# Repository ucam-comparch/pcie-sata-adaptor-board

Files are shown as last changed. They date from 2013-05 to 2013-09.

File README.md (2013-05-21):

This is a printed circuit board to breakout an 8-lane PCI Express socket into
8x SATA channels, which we have used with Terasic DE4 FPGA boards.

THIS IS NOT A SATA CONTROLLER, it merely uses SATA sockets for the physical
connections as the sockets and cables are cheap, and have good signal integrity.
What you put down the PCIe lanes is up to your FPGA configuration.

Images (the first version with a few hand bugfixes):
Front board image
Rear board image

The design was created using Eagle PCB, but the gerber files should be
usable even if you don't have Eagle.

The 4-layer board was fabricated by rak.co.uk using a standard-ish stackup:  
0.2mm double sided  
2 pre-pregs (0.15mm)  
0.8mm unclad board  
2 pre-pregs (0.15mm)  
0.2mm double sided  
Total 1.5-1.6mm  

They don't provide controlled impedance boards but our design is sized to
have the correct impedances according to this stackup.

In addition ports are provided for:  
SATA power (3.3V and 12V)  
Altera USB Blaster-compatible JTAG port  

Since we couldn't source SATA power connectors without data, the data part
of the SATA power connector is connected to some I/Os on the PCIe connector. 
This can be used for low-speed signalling from the FPGA.

If you connect a USB Blaster to the JTAG port you need to fit components to
VREF_SRC to supply the correct VREF.  The DE4 uses 2.5V - we fit resistors
68R from 3V3 to VREF and 220R from VREF to ground.

R1/R2/R3 provide access to the unused lines on the JTAG cable, or means to
ground them to reduce noise.

Computer Architecture Group, University of Cambridge Computer Laboratory  
May 2013  
http://www.cl.cam.ac.uk/research/comparch/  

Copyright (c) 2013, Simon Moore  
All rights reserved.  

Redistribution and use in source and binary forms, with or without
modification, are permitted provided that the following conditions are met:

 1. Redistributions of source code must retain the above copyright notice, this
    list of conditions and the following disclaimer.

 2. Redistributions in binary form must reproduce the above copyright
    notice, this list of conditions and the following disclaimer in the
    documentation and/or other materials provided with the distribution.

THIS SOFTWARE IS PROVIDED BY THE COPYRIGHT HOLDERS AND CONTRIBUTORS "AS IS"
AND ANY EXPRESS OR IMPLIED WARRANTIES, INCLUDING, BUT NOT LIMITED TO,
THE IMPLIED WARRANTIES OF MERCHANTABILITY AND FITNESS FOR A PARTICULAR
PURPOSE ARE DISCLAIMED.  IN NO EVENT SHALL THE COPYRIGHT HOLDER OR
CONTRIBUTORS BE LIABLE FOR ANY DIRECT, INDIRECT, INCIDENTAL, SPECIAL,
EXEMPLARY, OR CONSEQUENTIAL DAMAGES (INCLUDING, BUT NOT LIMITED TO,
PROCUREMENT OF SUBSTITUTE GOODS OR SERVICES; LOSS OF USE, DATA, OR
PROFITS; OR BUSINESS INTERRUPTION) HOWEVER CAUSED AND ON ANY THEORY OF
LIABILITY, WHETHER IN CONTRACT, STRICT LIABILITY, OR TORT (INCLUDING
NEGLIGENCE OR OTHERWISE) ARISING IN ANY WAY OUT OF THE USE OF THIS
SOFTWARE, EVEN IF ADVISED OF THE POSSIBILITY OF SUCH DAMAGE.

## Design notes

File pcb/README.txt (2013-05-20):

File extensions:
Eagle schematic: .sch
Eagle board: .brd
Eagle library: .lbr

Gerber layers:
.crc: component side solder cream frame
.plc: component side silkscreen
.stc: component side solder mask
.cmp: component side copper
.ly2: inner layer copper (layer 2)
.l15: inner layer copper (layer 15)
.sol: solder side copper
.sts: solder side solder mask
.pls: solder side silkscreen
.crs: solder side solder cream frame

Drill files:
.drd: Excellon drill file
.dri: Drill station info file

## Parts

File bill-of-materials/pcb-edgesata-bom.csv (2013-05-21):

PCIe to SATA adaptor PCB parts list
User part no | Supplier | Supplier part no | Qty per assembly | Description | Mfr/Part | Unit price exc breaks | Total price | Notes
 | Farnell | 1753904 | 1 | SOCKET, PCI-E, 2X49, EDGE | SAMTEC - PCIE-098-02-F-D-EM2 | 7.98 | 7.98
 | Farnell | 1519801 | 8 | HEADER, SATA, VERTICAL, 1.27MM, 7WAY | MOLEX - 47155-4001 | 0.28 | 2.24
 | RS | 212-806 | 1 | SATA 22P DEVICE PLUG RIGHT ANGLE PTH | 3M 5622-4100-ML | 1.772 | 1.772
 | Farnell | 1099245 | 1 | HEADER, RIGHT ANGLE, 10WAY | MULTICOMP - MC9A22-1034 | 0.39 | 0.39
 | Farnell | 3418492 | 2 | HEADER, 2ROW, 6WAY | TE CONNECTIVITY / AMP 826632-3 | 0.22 | 0.44
0R-0805 |  |  | 3 | 0R 0805 resistor |  |  |  | Optional
 | RAK |  | 1 | Printed circuit board | UNI14 - 97956

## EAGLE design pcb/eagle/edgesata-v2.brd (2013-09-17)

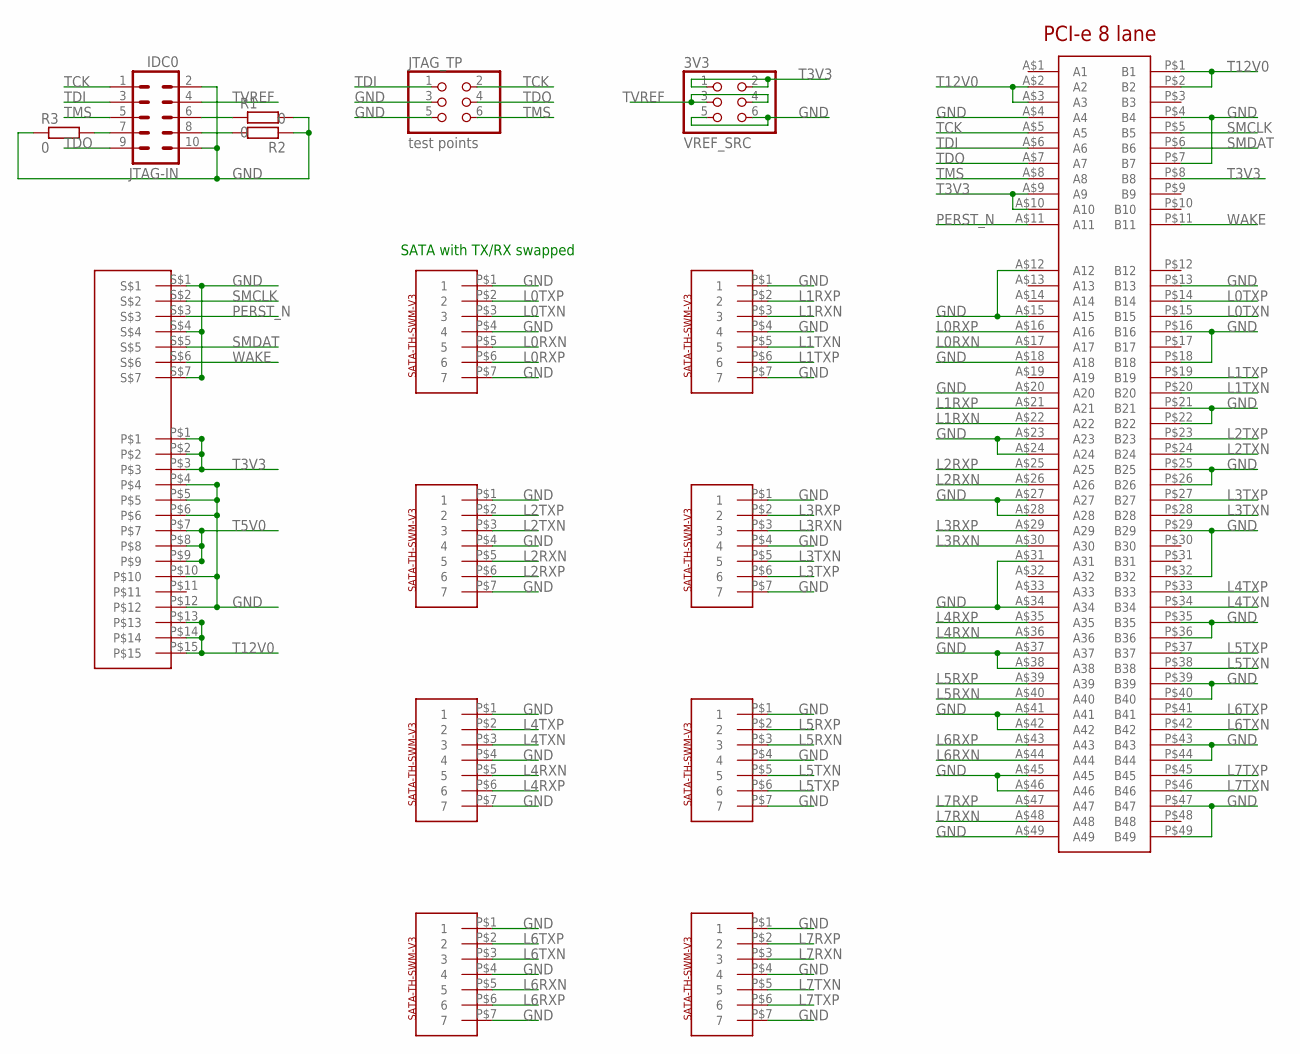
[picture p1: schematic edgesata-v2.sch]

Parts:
3V3: VREF_SRC; 2X03
JTAG-IN: IDC0; MA05-2
JTAG_TP: test points; 2X03
LANE0, LANE1, LANE2, LANE3, LANE4, LANE5, LANE6, LANE7: SATA-TH-SWM-V3
R1, R2, R3: 0; R0805W
U$1: SATA-POWER-V1
U$8: PCIE-EDGE-8LANE-V1

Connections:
GND: 3V3.5, 3V3.6, JTAG-IN.2, JTAG-IN.10, JTAG_TP.3, JTAG_TP.5, LANE0.P$1 (1), LANE0.P$4 (4), LANE0.P$7 (7), LANE1.P$1 (1), LANE1.P$4 (4), LANE1.P$7 (7), LANE2.P$1 (1), LANE2.P$4 (4), LANE2.P$7 (7), LANE3.P$1 (1), LANE3.P$4 (4), LANE3.P$7 (7), LANE4.P$1 (1), LANE4.P$4 (4), LANE4.P$7 (7), LANE5.P$1 (1), LANE5.P$4 (4), LANE5.P$7 (7), LANE6.P$1 (1), LANE6.P$4 (4), LANE6.P$7 (7), LANE7.P$1 (1), LANE7.P$4 (4), LANE7.P$7 (7), R1.2, R2.1, R3.1, U$1.P$4, U$1.P$5, U$1.P$6, U$1.P$10, U$1.P$12, U$1.S$1, U$1.S$4, U$1.S$7, U$8.A$4 (A4), U$8.A$12 (A12), U$8.A$15 (A15), U$8.A$18 (A18), U$8.A$20 (A20), U$8.A$23 (A23), U$8.A$24 (A24), U$8.A$27 (A27), U$8.A$28 (A28), U$8.A$31 (A31), U$8.A$34 (A34), U$8.A$37 (A37), U$8.A$38 (A38), U$8.A$41 (A41), U$8.A$42 (A42), U$8.A$45 (A45), U$8.A$46 (A46), U$8.A$49 (A49), U$8.P$4 (B4), U$8.P$7 (B7), U$8.P$13 (B13), U$8.P$16 (B16), U$8.P$18 (B18), U$8.P$21 (B21), U$8.P$22 (B22), U$8.P$25 (B25), U$8.P$26 (B26), U$8.P$29 (B29), U$8.P$32 (B32), U$8.P$35 (B35), U$8.P$36 (B36), U$8.P$39 (B39), U$8.P$40 (B40), U$8.P$43 (B43), U$8.P$44 (B44), U$8.P$47 (B47), U$8.P$49 (B49)
L0RXN: LANE0.P$5 (5), U$8.A$17 (A17)
L0RXP: LANE0.P$6 (6), U$8.A$16 (A16)
L0TXN: LANE0.P$3 (3), U$8.P$15 (B15)
L0TXP: LANE0.P$2 (2), U$8.P$14 (B14)
L1RXN: LANE1.P$3 (3), U$8.A$22 (A22)
L1RXP: LANE1.P$2 (2), U$8.A$21 (A21)
L1TXN: LANE1.P$5 (5), U$8.P$20 (B20)
L1TXP: LANE1.P$6 (6), U$8.P$19 (B19)
L2RXN: LANE2.P$5 (5), U$8.A$26 (A26)
L2RXP: LANE2.P$6 (6), U$8.A$25 (A25)
L2TXN: LANE2.P$3 (3), U$8.P$24 (B24)
L2TXP: LANE2.P$2 (2), U$8.P$23 (B23)
L3RXN: LANE3.P$3 (3), U$8.A$30 (A30)
L3RXP: LANE3.P$2 (2), U$8.A$29 (A29)
L3TXN: LANE3.P$5 (5), U$8.P$28 (B28)
L3TXP: LANE3.P$6 (6), U$8.P$27 (B27)
L4RXN: LANE4.P$5 (5), U$8.A$36 (A36)
L4RXP: LANE4.P$6 (6), U$8.A$35 (A35)
L4TXN: LANE4.P$3 (3), U$8.P$34 (B34)
L4TXP: LANE4.P$2 (2), U$8.P$33 (B33)
L5RXN: LANE5.P$3 (3), U$8.A$40 (A40)
L5RXP: LANE5.P$2 (2), U$8.A$39 (A39)
L5TXN: LANE5.P$5 (5), U$8.P$38 (B38)
L5TXP: LANE5.P$6 (6), U$8.P$37 (B37)
L6RXN: LANE6.P$5 (5), U$8.A$44 (A44)
L6RXP: LANE6.P$6 (6), U$8.A$43 (A43)
L6TXN: LANE6.P$3 (3), U$8.P$42 (B42)
L6TXP: LANE6.P$2 (2), U$8.P$41 (B41)
L7RXN: LANE7.P$3 (3), U$8.A$48 (A48)
L7RXP: LANE7.P$2 (2), U$8.A$47 (A47)
L7TXN: LANE7.P$5 (5), U$8.P$46 (B46)
L7TXP: LANE7.P$6 (6), U$8.P$45 (B45)
unnamed: JTAG-IN.7, R3.2
unnamed: JTAG-IN.6, R1.1
unnamed: JTAG-IN.8, R2.2
PERST_N: U$1.S$3, U$8.A$11 (A11)
SMCLK: U$1.S$2, U$8.P$5 (B5)
SMDAT: U$1.S$5, U$8.P$6 (B6)
T3V3: 3V3.1, 3V3.2, U$1.P$1, U$1.P$2, U$1.P$3, U$8.A$9 (A9), U$8.A$10 (A10), U$8.P$8 (B8)
T5V0: U$1.P$7, U$1.P$8, U$1.P$9
T12V0: U$1.P$13, U$1.P$14, U$1.P$15, U$8.A$2 (A2), U$8.A$3 (A3), U$8.P$1 (B1), U$8.P$2 (B2)
TCK: JTAG-IN.1, JTAG_TP.2, U$8.A$5 (A5)
TDI: JTAG-IN.3, JTAG_TP.1, U$8.A$6 (A6)
TDO: JTAG-IN.9, JTAG_TP.4, U$8.A$7 (A7)
TMS: JTAG-IN.5, JTAG_TP.6, U$8.A$8 (A8)
TVREF: 3V3.3, 3V3.4, JTAG-IN.4
WAKE: U$1.S$6, U$8.P$11 (B11)

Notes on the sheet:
SATA with TX/RX swapped

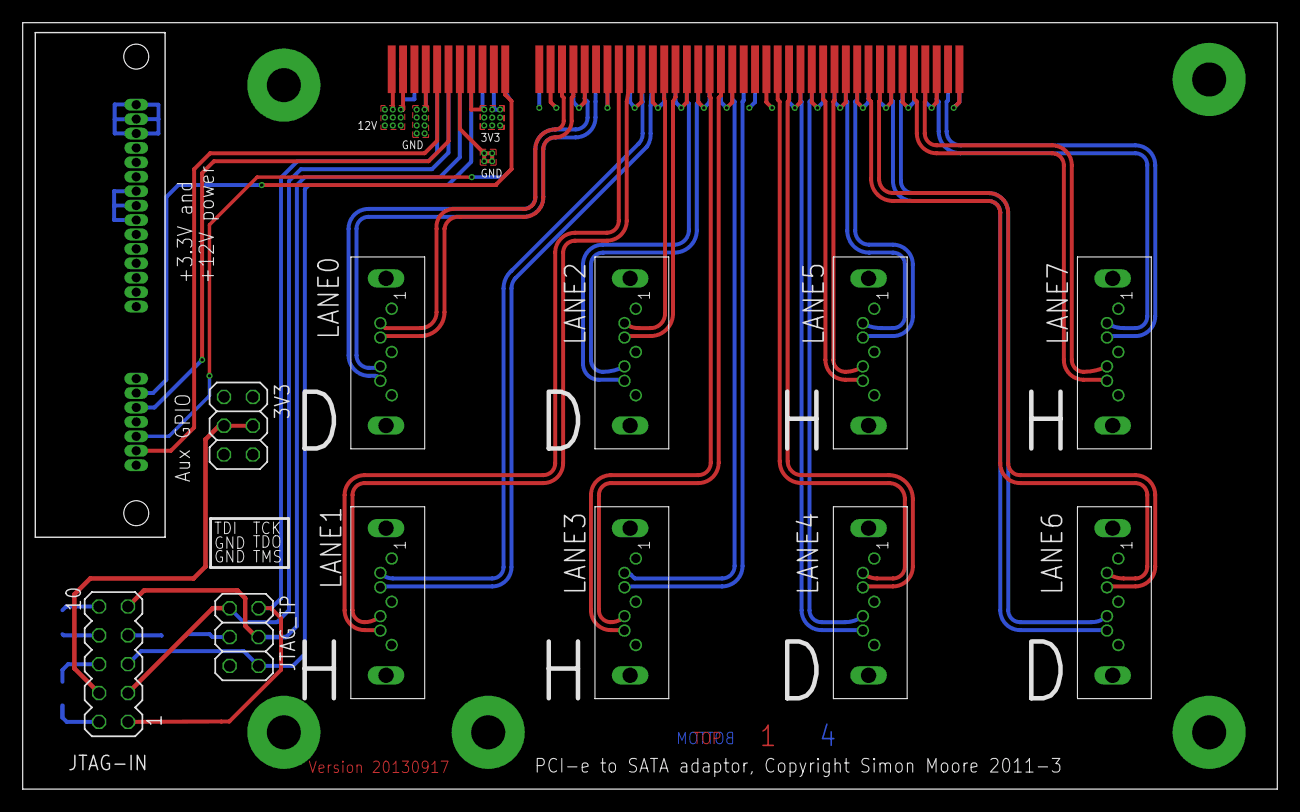
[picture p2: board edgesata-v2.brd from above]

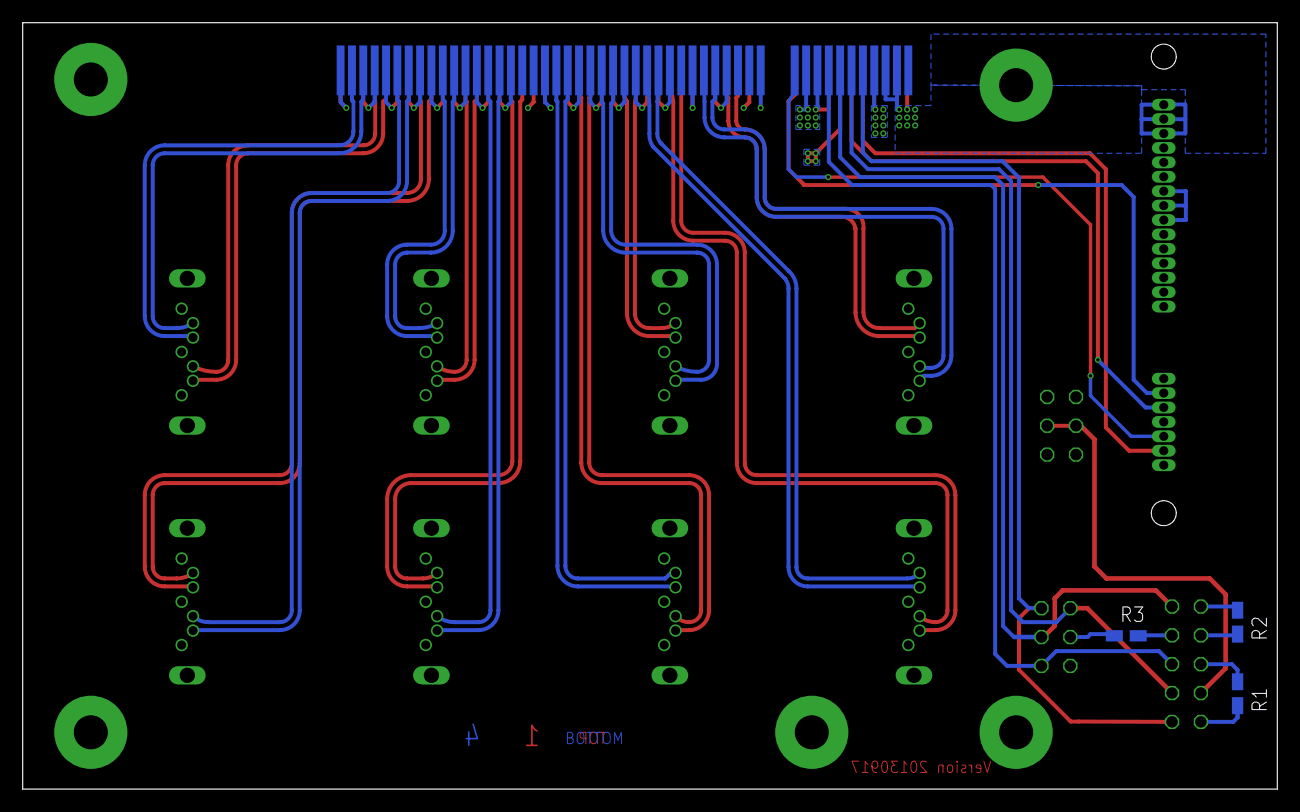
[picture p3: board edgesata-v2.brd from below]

Board: 4 copper layers, 110.5 x 67.5 mm, 16 parts (3 on the bottom side), 48 nets.

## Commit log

2013-05-20 Import designs for fabricated board, version 20110809. Bugs currently remaining: USB Blaster JTAG TDI/TDO crossed 4th aux GPIO is connected to PRSNT1# board detect line, not PERST# GPIO
    [edgesata-v2.brd, edgesata-v2.sch]
2013-05-20 Split up files into eagle/gerber/drill directories
    [edgesata-v2.brd, edgesata-v2.sch]
2013-05-21 Bug fix version - fix problems with crossed JTAG lines and incorrect 4th aux GPIO pins. Not yet tested by fabrication.
    [edgesata-v2.brd, edgesata-v2.sch, pcb-edgesata-bom.csv]
2013-05-21 Generate drill files for new revision of board
2013-09-17 Fix unrouted net to JTAG pulldown resistor R1. Not yet fabrication tested.
    [edgesata-v2.brd]

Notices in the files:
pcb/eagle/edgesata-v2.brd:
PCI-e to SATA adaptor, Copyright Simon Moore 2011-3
